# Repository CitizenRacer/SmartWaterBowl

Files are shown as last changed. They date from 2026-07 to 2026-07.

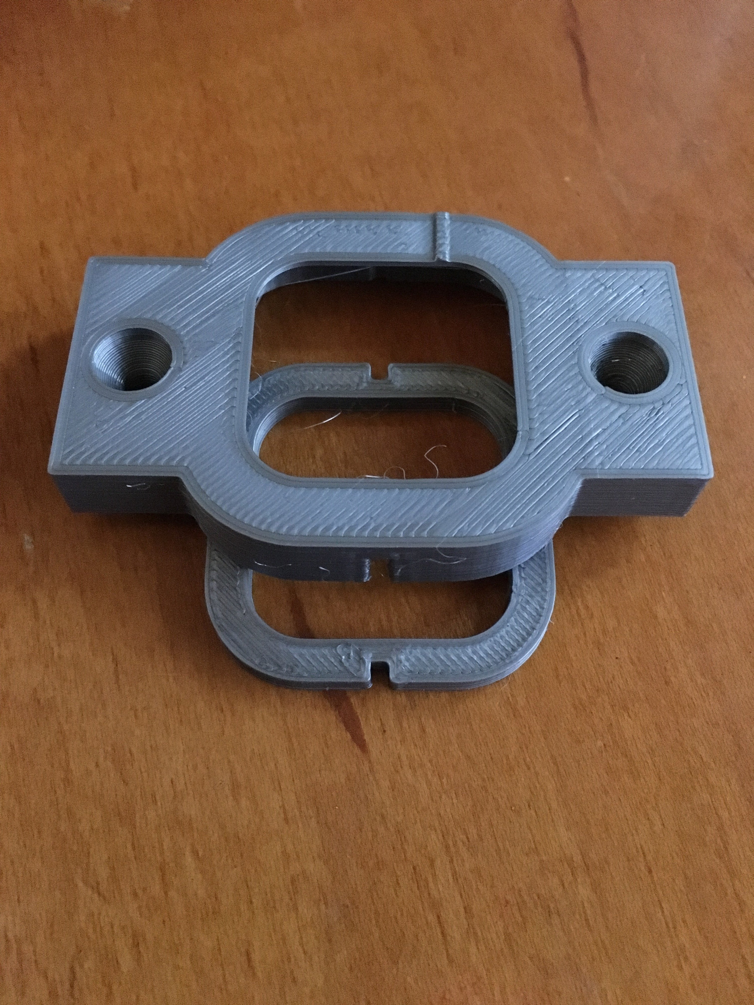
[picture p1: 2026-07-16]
hardware/loadcell-brackets/IMG_1209.jpg

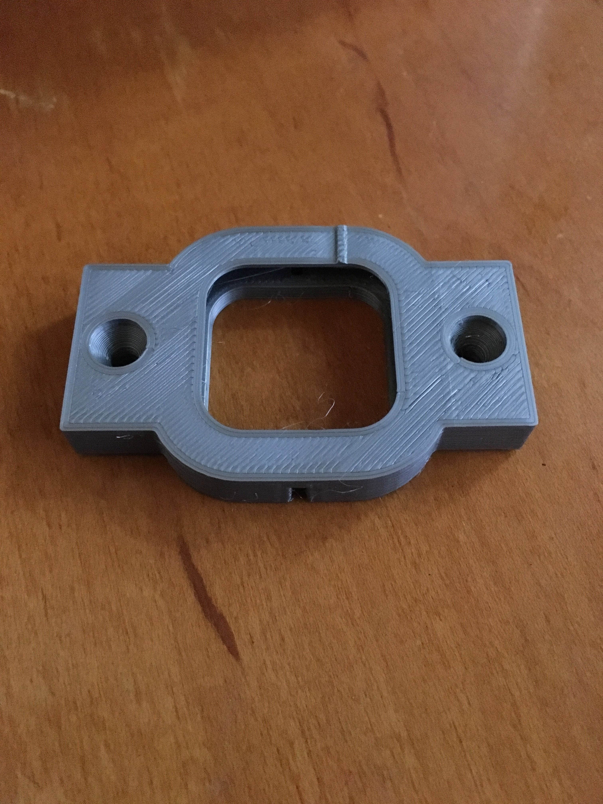
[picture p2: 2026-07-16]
hardware/loadcell-brackets/IMG_1208.jpg

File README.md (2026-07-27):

# SmartWaterBowl

SmartWaterBowl is an ESPHome-based scale for monitoring the amount of water in a shared dog bowl and publishing the measurements to Home Assistant. The repository also includes an optional clip-on fountain-tube mount for circulating water back into the bowl.

Four load sensors support the bowl platform. Their signals are combined, digitized by an HX711 amplifier, and read by an ESP32-S3 running ESPHome.

> **Current status:** The enclosure fit and ESP32 cradle fit were physically verified in earlier revisions, including the V35 ESP32 geometry retained in the current **V40** source. V40 replaces the diagonal HX711 support reliefs with horizontal east-west flats: the southern support pair faces north and the northern support pair faces south. The load-cell bracket design, repaired STL files, initial ESPHome firmware, and parametric fountain-tube mount are tracked in the repository; V40 physical validation, wiring validation, calibration, the bowl platform, and physical validation of the fountain mount remain in development.

## System overview

```text
Water bowl and platform
        ↓
4 × load sensors in printed brackets
        ↓
SparkFun Load Sensor Combinator
        ↓
SparkFun HX711 Load Cell Amplifier
        ↓
ESP32-S3 SuperMini running ESPHome
        ↓
Home Assistant
```

## Project goals

- Measure the current amount of water in the bowl.
- Track water added and water consumed over time.
- Publish measurements to Home Assistant through ESPHome.
- Keep powered electronics protected in a separate enclosure.
- Make the mechanical and electronics mounting parts reproducible with a 3D printer.
- Support an optional low-voltage recirculating fountain with a removable, rigidly supported tube path.

## Hardware

| Component | Purpose |
|---|---|
| 4 × SparkFun 50 kg load sensors | Support and weigh the bowl platform |
| 3D-printed load-cell brackets | Hold each load sensor and transfer platform load |
| SparkFun Load Sensor Combinator | Combines the four load sensors into one bridge output |
| SparkFun HX711 Load Cell Amplifier | Digitizes the load-cell signal |
| ESP32-S3 SuperMini | Runs ESPHome and publishes measurements over Wi-Fi |
| LeMotech 115 × 90 × 55 mm enclosure — Amazon ASIN `B0895J3SWL` | Protects the electronics |
| USB-C panel-mount extension | Provides external power and programming access |
| PG7 cable glands | Seal the load-sensor cable entries |
| 22 AWG silicone wire | Internal wiring |
| JST-PH connectors | Provide disconnectable internal connections |
| M3 × 6 mm machine screws | Permanently secure the two SparkFun boards directly to printed plastic bosses |
| Optional low-voltage submersible pump and 10 mm OD tubing | Recirculate water through the clip-on fountain mount |

## Repository layout

```text
firmware/
└── esphome_water_bowl.yaml
hardware/
├── enclosure/
│   └── water_bowl_electronics_carrier.scad
├── fountain/
│   └── water_bowl_fountain_mount.scad
└── loadcell-brackets/
    ├── 50kgLoadcell-VersionF.stl
    ├── 50kgLoadcell-VersionF-2021.stl
    ├── source CAD and preview images
    ├── README.txt
    └── LICENSE.txt
```

Additional directories will be added as wiring documentation and the bowl-platform design are completed.

## ESPHome firmware

The current ESPHome configuration is:

[`firmware/esphome_water_bowl.yaml`](firmware/esphome_water_bowl.yaml)

It currently provides:

- Current water-only weight after subtracting a configurable empty-bowl weight
- Latest settled refill weight, used as the 100% reference
- Percentage full based on the most recent qualifying refill
- Timestamp of the last manual or automatic tare
- A Home Assistant tare button
- Automatic tare detection after a drop greater than one pound, confirmed only after the platform remains near zero for five seconds
- Refill detection requiring approximately eight fluid ounces of added water and a five-second settling period

The initial pin assignment is:

| HX711 signal | ESP32-S3 pin |
|---|---|
| DOUT | GPIO5 |
| CLK | GPIO6 |

The `counts_per_lb` substitution is currently a placeholder and must be replaced after physical calibration. Wi-Fi, API encryption, OTA, and fallback access-point credentials are expected in the ESPHome secrets file.

## Electronics carrier

The current carrier source is:

[`hardware/enclosure/water_bowl_electronics_carrier.scad`](hardware/enclosure/water_bowl_electronics_carrier.scad)

The filename remains stable across revisions. The printed revision is controlled by the `board_version` value inside the SCAD file and is physically raised on the carrier.

The current board revision is **V40**.

### Supported hardware

The carrier is designed for the LeMotech 115 × 90 × 55 mm enclosure, Amazon ASIN `B0895J3SWL`, and holds:

- SparkFun Load Sensor Combinator
- SparkFun HX711 Load Cell Amplifier
- ESP32-S3 SuperMini

### Carrier features

- Four measured 3.4 mm enclosure mounting holes
- Four support locations per SparkFun board
- Two diagonal M3 screw bosses and two diagonal locator pins per SparkFun board
- Printed 2.80 mm thread-forming pilot holes for M3 screws, so no drilling is required
- Pilot holes extend 1.0 mm into the 2.0 mm carrier base while leaving a 1.0 mm floor
- East-west relief flats on all four HX711 support pads for clearance around soldered underside pins
- North-facing flats on the two southern HX711 supports and south-facing flats on the two northern supports
- Each HX711 flat is tangent to the 3.18 mm central post envelope
- Fully round, unchanged support pads for the Load Sensor Combinator
- Captured-rail cradle for the ESP32-S3 SuperMini
- Physically verified V35 ESP32 cradle position preserved unchanged
- 0.635 mm ESP32 header-pin channels, sized for measured 0.63 mm-wide pins
- Two pairs of optional zip-tie slots
- Raised board-revision marking
- Thin `fit_check` mode for verifying enclosure fit before printing the complete carrier
- Validation that rejects unsupported `mode` values instead of silently producing an incomplete part

The M3 × 6 mm screws are intended to form threads directly in the printed plastic. The 2.80 mm holes are thread-forming pilots, not clearance holes: an M3 screw should be driven into them rather than dropping freely through. Because the boards are not expected to be removed after assembly, this avoids heat-set inserts while still providing positive retention. Tighten the screws only until the boards are secure; excessive torque can strip the printed threads or damage the PCB.

V38 increased the pilot-hole diameter from 2.55 mm to 2.80 mm after the V37 print accepted an M2.5 screw but was too tight for the intended M3 fastener.

V39 introduced reliefs on all four HX711 support pads, but oriented each flat diagonally toward the board center. V40 corrects the orientation without changing the relief depth: both flats on the southern row run east-west and face north, while both flats on the northern row run east-west and face south. The Load Sensor Combinator supports, board coordinates, support heights, M3 pilots, locator pins, ESP32 cradle, zip-tie slots, and enclosure geometry remain unchanged.

The enclosure mounting-hole coordinates are expressed in the final carrier-local coordinate frame and were adjusted empirically against the enclosure. Changing `wall_clearance` requires revalidating those four coordinates.

The current design omits the earlier side-retention bumps because their geometry did not reach the nominal enclosure wall. The carrier is secured by the four enclosure mounting screws.

### Generating the carrier

1. Open the SCAD file in [OpenSCAD](https://openscad.org/).
2. Set the mode near the top of the file:

   ```scad
   mode = "carrier";
   ```

   Available modes:

   - `"fit_check"` creates a thin enclosure-fit test plate without the board holders.
   - `"carrier"` creates the complete electronics carrier.

   Any other value stops rendering with an explanatory assertion error.

3. Render the model with **F6**.
4. Export it as an STL.
5. Slice and print it flat on the build plate.

Suggested starting print settings:

- 0.20 mm layer height or finer
- At least three walls
- PLA, PETG, or ASA

PETG or ASA should provide more durable screw threads than brittle PLA, but PLA is acceptable for a one-time installation when the screws are tightened carefully.

Confirm dimensions, tolerances, and material suitability for the actual enclosure and operating environment before committing to a complete build.

## Load-cell brackets

The selected bracket design is **50kg Loadcell Bracket versionF** by Thingiverse user **patrick3345**:

- Original source: <https://www.thingiverse.com/thing:2624188>
- License: Creative Commons Attribution, as stated in the supplied `LICENSE.txt`
- Preserved attribution and source files: [`hardware/loadcell-brackets/`](hardware/loadcell-brackets/)

The two STL files in this directory have been repaired for reliable slicing while retaining their original filenames. The original README, license, source CAD files, preview images, and project fit-test photos remain beside them so attribution and design context stay together.

## Fountain tube mount

The optional fountain mount source is:

[`hardware/fountain/water_bowl_fountain_mount.scad`](hardware/fountain/water_bowl_fountain_mount.scad)

It is a parametric clip-on guide for nominal 10 mm OD flexible tubing. The tube follows an open candy-cane-shaped trough, rises 100 mm above the bowl rim, curves over the bowl, and points the outlet downward and inward. The groove is cut through at both ends so the tubing can sit at full depth throughout the guide. Three pairs of slots accept small zip ties for removable retention.

The key dimensions near the top of the file are:

```scad
tube_od = 10.0;
bowl_rim_thickness = 6.0;
riser_height_above_rim = 100.0;
bend_radius = 22.0;
outlet_inward_angle = 25.0;
outlet_length = 33.0;
```

Measure the actual bowl rim and tubing before printing. Print the mount with its broad flat rear face on the build plate and the tube groove facing upward. The model is intended to print without supports. PETG or ASA is preferred for durability around water and repeated clipping, but material and tubing suitability for the intended water-contact environment must be evaluated before use.

## Current progress

- [x] Select the load sensors and electronics
- [x] Purchase the core electronics and wiring hardware
- [x] Measure the LeMotech enclosure
- [x] Design and fit-test the electronics carrier
- [x] Preserve the physically verified V35 ESP32 holder geometry
- [x] Create carrier board revision V40
- [x] Replace ineffective snap tabs with direct-threaded M3 board retention
- [x] Remove ineffective side-retention bumps
- [x] Deepen the printed M3 pilot holes while retaining a solid base floor
- [x] Increase the SparkFun-board pilot holes to 2.80 mm for M3 thread forming
- [x] Add HX711 support relief for soldered underside-pin clearance
- [x] Orient the southern HX711 reliefs north and the northern reliefs south
- [x] Keep the Load Sensor Combinator supports unchanged
- [x] Adopt a stable carrier filename independent of board revision
- [x] Select and archive the load-cell bracket design with attribution
- [x] Repair the bracket STL files for slicing
- [x] Select initial ESP32 pin assignments
- [x] Add the initial ESPHome configuration
- [x] Add the parametric clip-on fountain tube mount source
- [ ] Physically print and validate carrier board revision V40
- [ ] Physically print and validate the fountain mount against the bowl and tubing
- [ ] Integrate the brackets into the bowl platform
- [ ] Validate the wiring and pin assignments on assembled hardware
- [ ] Calibrate the assembled scale
- [ ] Add Home Assistant dashboards and automations
- [ ] Validate long-term stability and water resistance

## Versioning convention

The carrier filename does not include a revision number. Future carrier revisions will continue to use:

```text
hardware/enclosure/water_bowl_electronics_carrier.scad
```

The revision number must instead be updated in the SCAD file:

```scad
board_version = "V40";
```

This value is rendered directly onto the printed carrier, making the physical revision identifiable without changing repository paths or documentation links.

The fountain mount also uses a stable descriptive path:

```text
hardware/fountain/water_bowl_fountain_mount.scad
```

## Repository maintenance

Every repository change should include a review of this README to verify that it remains factually correct and easy to understand. Update it whenever a change affects:

- File or directory names
- Hardware selections
- Board revision or mechanical design
- Wiring or pin assignments
- ESPHome configuration
- Calibration procedure
- Build status or remaining work

Readability improvements should be made whenever they clarify setup, operation, or project status.

## Calibration plan

Once assembled, the scale will need at least two calibration points:

1. Record the unloaded HX711 reading with the empty platform installed.
2. Place a known calibration weight on the platform and record the loaded reading.
3. Use those values to calculate the scale factor in ESPHome.
4. Verify the result with several known weights across the expected operating range.

The scale should be tared with the permanent platform hardware installed but without the removable bowl. Enter the empty bowl's measured weight using the `Bowl Weight` entity so the published weight represents water only.

## Water protection

This project places powered electronics near a water bowl. Use only low-voltage power, route cables through sealed glands, provide strain relief, and keep the electronics enclosure physically separated from areas where spilled water can collect.

The printed electronics carrier, load-cell brackets, and fountain mount are mechanical parts and are not themselves waterproof barriers. Use pump, tubing, fasteners, and printed materials suitable for the intended water-contact environment, and inspect and clean the fountain components regularly.

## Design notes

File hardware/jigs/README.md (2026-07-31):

# Smart Water Bowl fabrication jigs

This folder contains printable OpenSCAD jigs used to locate holes and repeat critical fabrication steps for the Smart Water Bowl hardware.

Generated STL files are intentionally not stored in the repository. Open the desired `.scad` file in OpenSCAD, render it with **F6**, and export an STL locally.

## `water_bowl_corner_hole_jig.scad`

### Purpose

Locates the two mounting holes for each 50 kg load-cell bracket at the four corners of the 16 × 11 × 1 inch cutting-board scale platform.

### Critical geometry

- Two 2.2 mm marking holes
- Mounting-hole spacing: 44.0 mm center to center
- Pattern center: 38.0 mm from each adjacent board edge
- Sized for a nominal 25.4 mm-thick cutting board
- Small inside-corner relief for rounded or beveled board edges
- Raised marking collars disabled with `collar_h = 0`

### Use

1. Place the jig on the underside of one cutting-board corner.
2. Seat both fences firmly against the adjacent board edges.
3. Keep the 82 mm side parallel to the board's 16-inch edge.
4. Mark through both holes with an awl, transfer punch, or a small drill bit turned by hand.
5. Rotate the jig around the board and repeat at all four corners.

### Printing

Print with the flat top plate on the build plate and the fences extending upward. No supports should be required.

Suggested starting settings:

- 0.20 mm layer height
- Four walls
- 25% infill
- PETG or ASA preferred; PLA is adequate for a temporary jig

### Validation note

The 44.0 mm mounting-hole spacing is the current prototype value. Compare a printed jig directly against a printed load-cell bracket before drilling the cutting board.

### Bracket attribution

The mounting geometry is based on **50kg Loadcell Bracket versionF** by Thingiverse user **patrick3345** (Patrick Laidlaw):

- Original source: https://www.thingiverse.com/thing:2624188
- License: Creative Commons Attribution, as preserved in `hardware/loadcell-brackets/LICENSE.txt`

## `water_bowl_enclosure_pilot_hole_jig.scad`

### Purpose

Locates the two cable-entry pilot holes, one in each long side of the LeMotech 115 × 90 × 55 mm enclosure base.

The holes align with the cable zip-tie pairs on `hardware/enclosure/water_bowl_electronics_carrier.scad`. The jig indexes from one outside short end of the enclosure and places both side holes at the same longitudinal station.

### Critical geometry

- Pilot-hole station: 43.85 mm from the indexed outside end
- Pilot-hole center height: 12 mm above the enclosure's outside bottom
- Printed locating-hole diameter: 3.30 mm for a nominal 1/8-inch pilot bit
- Flat drilling walls with no projecting bosses
- Short-end stop for repeatable positioning

The 43.85 mm station is derived from the enclosure wall thickness, carrier end clearance, and carrier zip-tie geometry. Those values are documented in the OpenSCAD source and should remain synchronized with the carrier design.

### Use

1. Print the jig flat on its bottom frame.
2. Place the empty enclosure base in the jig.
3. Press the selected short end firmly against the end stop.
4. Clamp the enclosure and jig together.
5. Drill through both flat pilot-hole locators.
6. Remove the jig.
7. Enlarge each enclosure hole to its final diameter with a step drill.

Do not run the step drill through the printed jig. The jig is only intended to establish the pilot-hole centers.

### Printing

Print exactly as modeled with the bottom frame on the build plate. The side walls are flat and no supports should be required.

PETG or ASA is recommended for better heat resistance and durability.

### Adjustable parameters

The main user-adjustable values near the top of the OpenSCAD file are:

- `pilot_d`
- `hole_height_from_bottom`
- `side_clearance`
- `side_wall_t`
- `side_wall_h`

## Adding another jig

Use a descriptive filename without a revision number. Add a section here that documents:

- What the jig is for
- The surfaces or edges it indexes from
- Critical dimensions
- Print orientation and support requirements
- How to use it
- Any measurements that must stay synchronized with another project file

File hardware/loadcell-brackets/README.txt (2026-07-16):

50kg Loadcell Bracket versionF by patrick3345 on Thingiverse: https://www.thingiverse.com/thing:2624188

Summary:
50kg Load Cell Bracket.  insert load cell and base into the holder and screw it down.

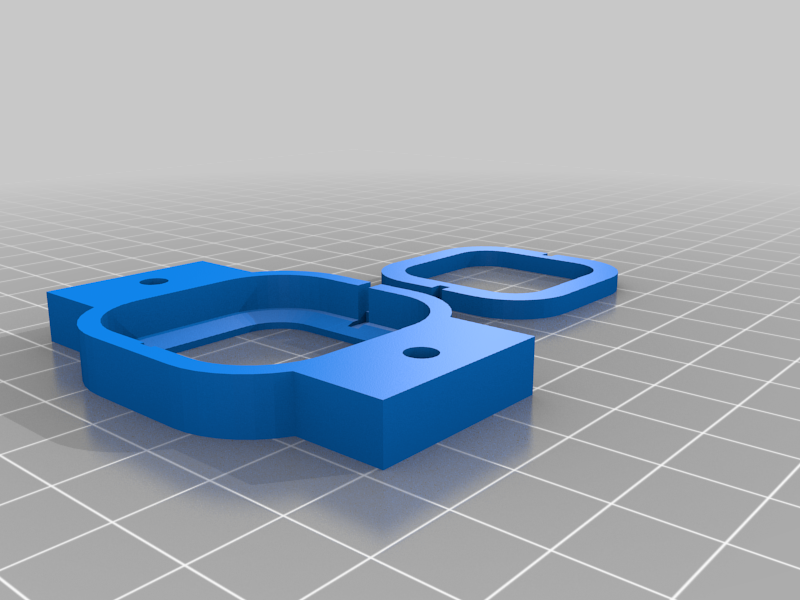
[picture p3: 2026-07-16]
hardware/loadcell-brackets/50kgLoadcell-VersionF-2021.png

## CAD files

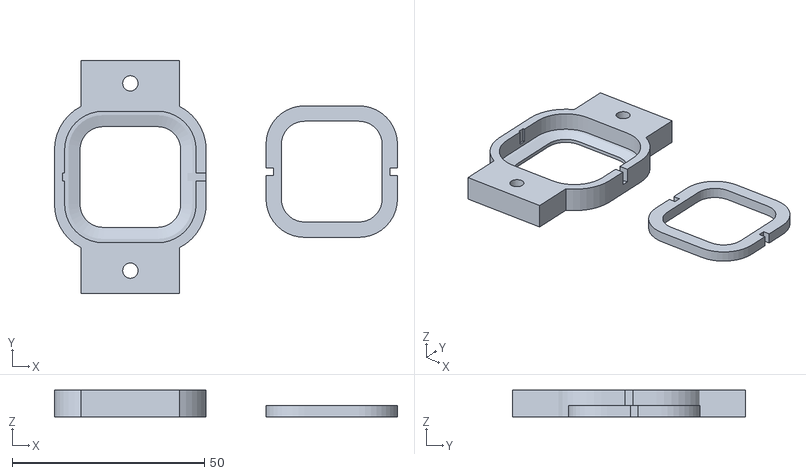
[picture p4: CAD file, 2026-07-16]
hardware/loadcell-brackets/50kgLoadcell-VersionF-2021.stl
89.2 x 60.7 x 7.00

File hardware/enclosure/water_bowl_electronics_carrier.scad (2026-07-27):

/*
ChatGPT ESPHome Water Bowl Scale
LeMotech 115 x 90 x 55 mm electronics carrier - V40
LeMotech enclosure Amazon ASIN: B0895J3SWL

V40 change from V39:
- Replaced the diagonal HX711 support-pad reliefs with east-west flat faces.
- The two southern HX711 supports have north-facing flats; the two northern supports have south-facing flats.
- Each flat is tangent to the outside of the 3.18 mm central post envelope.
- The Load Sensor Combinator supports and all other V39 geometry are unchanged.

Units and coordinate conventions:
- All dimensions are millimeters unless otherwise noted.
- X increases from the carrier's left edge to its right edge (west to east).
- Y increases from the carrier's lower end toward its upper end (south to north).
- Z increases upward from the bottom face of the printed carrier.
- Board positions and enclosure mounting-hole coordinates use the final carrier-local frame.

Fit-sensitive geometry:
- The ESP32 cradle position and 0.635 mm pin channels were physically verified in V35.
- The four enclosure mounting-hole coordinates were adjusted empirically against the enclosure.
- Do not alter those values without another physical fit test.
*/

$fn = 96;  // Facet count for cylinders; higher values look smoother but render more slowly.

// ---------- Output and plate settings ----------

// Selects the generated part:
// - "carrier": complete electronics carrier with board mounts and ESP32 cradle.
// - "fit_check": thin outline plate for checking enclosure fit only.
mode = "carrier";

// Text physically raised on the printed carrier.
board_version = "V40";

// Thickness of the complete carrier plate in "carrier" mode.
base_t = 2.0;

// Thickness of the reduced-cost enclosure test plate in "fit_check" mode.
fit_check_t = 1.0;

// Clearance removed from EACH side of the nominal enclosure interior dimensions.
// Increasing this reduces the finished carrier's width and length. The mounting-hole
// coordinates below do not automatically compensate and must then be revalidated.
wall_clearance = 0.65;

// Optional circular removal holes near the narrow end tabs. Disabled in V40.
finger_holes = false;

// Enables the two pairs of through-slots used for optional cable or component zip ties.
zip_tie_slots = true;

// Short dimension of each rectangular zip-tie slot.
zip_tie_slot_w = 2.4;

// Long dimension of each rectangular zip-tie slot.
zip_tie_slot_l = 10.0;

// Center-to-center Y separation between the two slots in each pair.
zip_tie_pair_spacing = 10.0;

// Enables the four enclosure-screw clearance holes in the carrier plate.
mount_holes = true;

// Diameter of each enclosure mounting through-hole; sized as M3 screw clearance.
mount_hole_d = 3.40;

// Enclosure mounting-hole centers in the FINAL carrier-local [X,Y] frame.
// These values were adjusted empirically against the physical LeMotech enclosure.
// Changing wall_clearance or the carrier outline requires revalidating all four points.
mount_points = [
    [5.98, 93.00],   // Upper-left enclosure mounting hole.
    [74.54, 93.13],  // Upper-right enclosure mounting hole.
    [6.38, 15.10],   // Lower-left enclosure mounting hole.
    [74.64, 15.07]   // Lower-right enclosure mounting hole.
];

// ---------- SparkFun board supports and fasteners ----------

// Height from the carrier's top surface to the underside of each SparkFun PCB.
standoff_h = 5.0;

// Outside diameter of every circular SparkFun support pad / screw boss.
standoff_od = 6.4;

// Printed thread-forming pilot diameter for M3 machine screws.
// This is intentionally smaller than the screw's 3.0 mm major diameter; the screw
// forms its own threads during the one-time installation rather than dropping through.
m3_pilot_d = 2.80;

// Additional pilot-hole depth below the top surface of the 2.0 mm carrier plate.
// At 1.0 mm this leaves a solid 1.0 mm floor beneath the hole.
m3_pilot_into_plate = 1.0;

// Diameter of the straight section of each non-threaded SparkFun locator pin.
prototype_pin_d = 3.18;

// Total locator-pin height above its circular support pad.
prototype_pin_h = 3.20;

// Height of the tapered lead-in at the top of each locator pin.
prototype_tip_h = 0.60;

// Diameter at the narrow top end of each locator-pin taper.
prototype_tip_d = 2.75;

// The HX711 pad relief stops at a tangent to this narrow central envelope.
hx_support_relief_d = prototype_pin_d;

// ---------- ESP32-S3 SuperMini cradle ----------

// Nominal free space added around each side of the ESP32 PCB envelope.
esp_clearance = 0.20;

// Thickness of each outside cradle rail surrounding the ESP32.
esp_rail_t = 1.40;

// Height of the outside cradle rails above the carrier plate.
esp_rail_h = 3.2;

// Gap between each outer and inner rail that captures an ESP32 header-pin row.
// This 0.635 mm value is intentionally retained from the physically verified V35 fit.
esp_pin_channel_w = 0.635;

// Thickness of each inner rail on the board side of a header-pin channel.
esp_inner_rail_t = 1.00;

// Height of each inner rail above the carrier plate.
esp_inner_rail_h = 3.20;

// Distance that each inner rail stops short of both cradle ends, allowing insertion.
esp_inner_rail_end_clearance = 1.50;

// ---------- Raised revision marking ----------

// Character size of the raised board revision text.
version_text_size = 5.0;

// Amount that the revision text rises above the carrier's top surface.
version_text_height = 0.60;

// Amount that the text extrusion overlaps the plate to guarantee a fused solid.
version_text_embed = 0.10;

// OpenSCAD font specification for the raised revision marking.
version_text_font = "Liberation Sans:style=Bold";

// [X,Y] anchor point for the revision text in the carrier-local frame.
version_text_pos = [8, 20];

// ---------- Enclosure and carrier outline ----------

// Nominal usable inside width of the LeMotech enclosure.
inner_w = 82.0;

// Nominal usable inside length of the LeMotech enclosure.
inner_h = 109.0;

// Nominal Y length of the wide middle section between the two narrow end tabs.
clear_middle_h = 87.0;

// Nominal X width of the narrow throat at each end of the enclosure.
end_throat_w = 46.0;

// Finished carrier width after removing wall_clearance from both left and right sides.
carrier_w = inner_w - 2*wall_clearance;

// Finished carrier length after removing wall_clearance from both ends.
carrier_h = inner_h - 2*wall_clearance;

// Finished Y length of the wide middle section after end clearances are applied.
middle_h = clear_middle_h - 2*wall_clearance;

// Finished X width of each narrow end tab.
end_tab_w = end_throat_w - 2*wall_clearance;

// Derived Y length of each narrow end tab; the upper and lower tabs are equal.
end_tab_h = (carrier_h-middle_h)/2;

// Left X boundary of each centered narrow end tab.
end_x0 = (carrier_w-end_tab_w)/2;

// Right X boundary of each centered narrow end tab.
end_x1 = end_x0+end_tab_w;

// Y coordinate where the lower narrow tab transitions into the wide center section.
mid_y0 = end_tab_h;

// Y coordinate where the wide center section transitions into the upper narrow tab.
mid_y1 = carrier_h-end_tab_h;

// ---------- Electronics board dimensions and positions ----------

// SparkFun Load Sensor Combinator nominal PCB width and height.
comb_w = 30.48;
comb_h = 27.94;

// SparkFun HX711 Load Cell Amplifier nominal PCB width and height.
hx_w = 30.48;
hx_h = 22.86;

// ESP32-S3 SuperMini PCB dimensions as used by the rotated cradle geometry.
// esp_y becomes the cradle's local X dimension; esp_x becomes its local Y dimension.
esp_x = 18.034;
esp_y = 25.4;

// Lower-left local origin of each SparkFun board footprint in carrier coordinates.
comb_pos = [7.0, 59.46];
hx_pos = [44.0, 62.0];

// Intentionally preserves the physically verified V35 ESP32 fit. This position uses
// the historical cradle origin rather than recentering the clearance envelope.
// Do not recenter or alter it without another physical fit test.
esp_pos = [(carrier_w-esp_y)/2, 14.0];

// SparkFun Combinator mounting-hole centers relative to comb_pos.
// Indices 0 and 3 receive M3 screw bosses; indices 1 and 2 receive locator pins.
comb_holes = [
    [27.94, 2.54],
    [2.54, 2.54],
    [27.94, 25.40],
    [2.54, 25.40]
];

// SparkFun HX711 mounting-hole centers relative to hx_pos.
// Hole order: lower-left, upper-left, lower-right, upper-right.
// Indices 0 and 3 receive M3 screw bosses; indices 1 and 2 receive locator pins.
hx_holes = [
    [2.54, 2.54],
    [2.54, 20.32],
    [27.94, 2.54],
    [27.94, 20.32]
];

// Relief-face direction for each HX711 support in the same order as hx_holes.
// The lower (southern) row faces north; the upper (northern) row faces south.
hx_relief_faces = ["north", "south", "north", "south"];

// ---------- Geometry modules ----------
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

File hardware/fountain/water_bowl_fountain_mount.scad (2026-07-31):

/*
  ChatGPT_Dog_Bowl_Candy_Cane_100mm_Lip_Hook.scad

  Revision of the original 100 mm candy-cane fountain holder.
  Keeps the original candy-cane trough, open ends, angled outlet, zip-tie
  slots, and flat print orientation. Replaces only the old thick-wall U-clip
  with a simple gravity hook for a stainless lip about 12.7 mm wide and
  1.6-3.2 mm thick. This revision removes the underside spring tab entirely.
*/

$fn = 48;

// Tubing
tube_od = 10.0;
tube_clearance = 0.35;
groove_depth = 5.6;

// Thin stainless bowl lip
lip_width = 12.7;
lip_width_clearance = 1.2;
lip_thickness_max = 3.2;
lip_vertical_clearance = 0.8;

// Hook structure
outside_leg_thickness = 4.0;
outside_leg_length = 28.0;   // Shorter, cleaner exterior leg
top_bridge_thickness = 5.0;
inside_stop_thickness = 3.5;
inside_stop_drop = 8.0;

// Overall printed thickness
part_depth = 12.0;

// Original candy-cane dimensions
riser_height_above_rim = 100.0;
bend_radius = 22.0;
outlet_inward_angle = 25.0;
outlet_length = 33.0;
end_groove_extension = 12.0;
guide_overlap = 3.0;
guide_side_wall = 3.0;
guide_extra_for_ties = 2.0;

// Zip ties
include_zip_tie_slots = true;
zip_tie_width = 3.2;
zip_tie_slot_clearance = 0.5;
zip_tie_slot_cross = 2.0;
zip_tie_side_offset = 2.0;

// Preview helpers
show_tube_preview = false;
show_lip_preview = false;

// Derived values
lip_gap_x = lip_width + lip_width_clearance;
lip_gap_y = lip_thickness_max + lip_vertical_clearance;

hook_inside_x = outside_leg_thickness + lip_gap_x;
hook_total_x = hook_inside_x + inside_stop_thickness;

hook_top_y = outside_leg_length;
lip_underside_y = hook_top_y - lip_gap_y;
inside_stop_bottom_y = hook_top_y - inside_stop_drop;

tube_r = tube_od / 2 + tube_clearance;
guide_half_width = tube_r + guide_side_wall + guide_extra_for_ties;

// Positive X points into the bowl.
riser_x = hook_total_x + guide_half_width - guide_overlap;
riser_start_y = 3.0;
riser_top_y = hook_top_y + top_bridge_thickness + riser_height_above_rim;

arc_center_x = riser_x + bend_radius;
arc_center_y = riser_top_y;
arc_end_angle = outlet_inward_angle;
outlet_direction = arc_end_angle - 90.0;

groove_center_z = part_depth + tube_r - groove_depth;

function arc_points(cx, cy, r, a0, a1, count) =
    [for (i = [0 : count])
        [cx + r * cos(a0 + (a1 - a0) * i / count),
         cy + r * sin(a0 + (a1 - a0) * i / count)]];

arc_path = arc_points(arc_center_x, arc_center_y, bend_radius, 180, arc_end_angle, 24);
arc_end = arc_path[len(arc_path) - 1];
outlet_end = [
    arc_end[0] + outlet_length * cos(outlet_direction),
    arc_end[1] + outlet_length * sin(outlet_direction)
];

tube_path = concat(
    [[riser_x, riser_start_y], [riser_x, riser_top_y]],
    arc_path,
    [outlet_end]
);

groove_start = [riser_x, riser_start_y - end_groove_extension];
groove_end = [
    outlet_end[0] + end_groove_extension * cos(outlet_direction),
    outlet_end[1] + end_groove_extension * sin(outlet_direction)
];
groove_path = concat([groove_start], tube_path, [groove_end]);

module stroke_2d(points, radius) {
    union() {
        for (i = [0 : len(points) - 2]) {
            hull() {
                translate(points[i]) circle(r = radius);
                translate(points[i + 1]) circle(r = radius);
            }
        }
    }
}

module swept_spheres(points, radius, z_center) {
    union() {
        for (i = [0 : len(points) - 2]) {
            hull() {
                translate([points[i][0], points[i][1], z_center]) sphere(r = radius);
                translate([points[i + 1][0], points[i + 1][1], z_center]) sphere(r = radius);
            }
        }
    }
}

module bowl_hook_profile_2d() {
    union() {
        // Long outside structural leg.
        square([outside_leg_thickness, hook_top_y + top_bridge_thickness]);

        // Bridge rests across the 1/2-inch rolled lip.
        translate([0, hook_top_y])
            square([hook_total_x, top_bridge_thickness]);

        // Short inside stop only; no full inner clamping leg.
        translate([hook_inside_x, inside_stop_bottom_y])
            square([
                inside_stop_thickness,
                hook_top_y + top_bridge_thickness - inside_stop_bottom_y
            ]);

        // Lead-in at bottom of outside leg.
        polygon(points = [
            [0, 0],
            [outside_leg_thickness, 0],
            [outside_leg_thickness, 4.0],
            [outside_leg_thickness - 1.2, 2.0]
        ]);
    }
}

module slot_pair_at(point, tangent_angle) {
    slot_along = zip_tie_width + zip_tie_slot_clearance;
    side_distance = tube_r + zip_tie_side_offset;

    for (normal_offset = [-side_distance, side_distance]) {
        translate([point[0], point[1], part_depth / 2])
            rotate([0, 0, tangent_angle])
                translate([0, normal_offset, 0])
                    cube([
                        slot_along,
                        zip_tie_slot_cross,
                        part_depth + 0.4
                    ], center = true);
    }
}

module all_zip_tie_slots() {
    if (include_zip_tie_slots) {
        slot_pair_at([riser_x, 19.0], 90);
        slot_pair_at([riser_x, riser_top_y - 12.0], 90);

        outlet_mid = [
            arc_end[0] + outlet_length * 0.52 * cos(outlet_direction),
            arc_end[1] + outlet_length * 0.52 * sin(outlet_direction)
        ];
        slot_pair_at(outlet_mid, outlet_direction);
    }
}

module solid_mount() {
    union() {
        linear_extrude(height = part_depth)
            bowl_hook_profile_2d();

        linear_extrude(height = part_depth)
            stroke_2d(tube_path, guide_half_width);

        // Revised gusset joins the original riser to the new hook.
        linear_extrude(height = part_depth)
            hull() {
                translate([
                    hook_inside_x + inside_stop_thickness / 2,
                    inside_stop_bottom_y + 2.5
                ]) circle(r = 3.0);

                translate([riser_x, 12.0])
                    circle(r = guide_half_width - 1.0);

                translate([
                    hook_inside_x + inside_stop_thickness / 2,
                    hook_top_y + top_bridge_thickness - 2.0
                ]) circle(r = 3.0);

                translate([
                    riser_x,
                    hook_top_y + top_bridge_thickness + 2.0
                ]) circle(r = guide_half_width - 1.0);
            }
    }
}

module fountain_mount() {
    difference() {
        solid_mount();
        swept_spheres(groove_path, tube_r, groove_center_z);
        all_zip_tie_slots();
    }
}

fountain_mount();

if (show_tube_preview) {
    %swept_spheres(
        tube_path,
        tube_od / 2,
        part_depth + tube_od / 2 - groove_depth
    );
}

if (show_lip_preview) {
    %color([0.65, 0.68, 0.72, 0.55])
        translate([
            outside_leg_thickness,
            hook_top_y - lip_thickness_max,
            -1
        ])
            cube([lip_width, lip_thickness_max, part_depth + 2]);

    %color([0.65, 0.68, 0.72, 0.35])
        translate([
            outside_leg_thickness + lip_width - 1.2,
            hook_top_y - lip_thickness_max - 35,
            -1
        ])
            cube([1.2, 35, part_depth + 2]);
}

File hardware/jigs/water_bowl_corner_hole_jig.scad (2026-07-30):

/*
ESPHome Water Bowl Scale
Corner Hole-Marking Jig v1.0 for a 16 x 11 x 1 inch cutting-board platform

Bracket source used for mounting geometry:
50kg Loadcell Bracket versionF by Patrick Laidlaw (patrick3345)
https://www.thingiverse.com/thing:2624188
CC BY, as preserved in the SmartWaterBowl repository.

Use:
- Put the jig on the UNDERSIDE of one board corner.
- Keep the 82 mm side parallel to a 16 inch edge.
- Push both fences fully against the board.
- Mark through both 2.2 mm guide holes with an awl or transfer punch.
- Rotate the physical jig around the board, always keeping the 82 mm side
  parallel to a 16 inch edge.

The two guide-hole centers are parameterized below so they can be revised after
an actual printed-foot fit check without redesigning the jig.
*/

$fn = 64;

jig_version = "v1.0";

// Board
board_t = 25.4;              // 1 inch
fit_clearance = 0.45;        // each fence-to-board clearance

// Jig body
plate_x = 82.0;              // along the board's 16 inch edge
plate_y = 76.0;              // along the board's 11 inch edge
plate_t = 4.0;
fence_t = 4.0;
fence_drop = board_t + 3.0;
corner_relief = 2.0;

// Hole pattern, corner-local coordinates in mm.
// Hole axis is parallel to the 16 inch board edge.
hole_spacing = 44.0;
foot_center_x = 38.0;
foot_center_y = 38.0;
mark_hole_d = 2.2;
collar_od = 8.0;
collar_h = 0.0;

hole_a = [foot_center_x-hole_spacing/2, foot_center_y];
hole_b = [foot_center_x+hole_spacing/2, foot_center_y];

module rounded_rect_2d(w,h,r) {
    offset(r=r) square([w-2*r,h-2*r]);
}

module plate_2d() {
    difference() {
        rounded_rect_2d(plate_x, plate_y, 4);
        for (p=[hole_a,hole_b]) translate(p) circle(d=mark_hole_d);
    }
}

module jig() {
    difference() {
        union() {
            linear_extrude(plate_t) plate_2d();

            // Fences descend from the underside of the top plate.
            translate([0,-fence_t,-fence_drop])
                cube([plate_x+fence_t, fence_t, fence_drop+plate_t]);
            translate([-fence_t,0,-fence_drop])
                cube([fence_t, plate_y+fence_t, fence_drop+plate_t]);

            // Reinforced marking collars are disabled in v1.0.
            for (p=[hole_a,hole_b])
                translate([p[0],p[1],plate_t])
                    difference() {
                        cylinder(h=collar_h,d=collar_od);
                        translate([0,0,-0.1]) cylinder(h=collar_h+0.2,d=mark_hole_d);
                    }
        }

        // Inside-corner relief so a slightly radiused cutting-board edge does
        // not keep the fences from seating fully.
        translate([-0.1,-0.1,-fence_drop-0.1])
            cube([corner_relief,corner_relief,fence_drop+plate_t+0.2]);
    }
}

jig();

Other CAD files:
hardware/loadcell-brackets/50kgLoadcell-VersionF.stl
hardware/jigs/water_bowl_enclosure_pilot_hole_jig.scad
hardware/loadcell-brackets/50kgLoadcell-VersionF-2021.skp
hardware/loadcell-brackets/50kgLoadcell-VersionF-2021_v1-Fusion360.f3d
hardware/loadcell-brackets/50kgLoadcell-VersionF.skp

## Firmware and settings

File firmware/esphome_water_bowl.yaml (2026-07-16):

# ESPHome configuration for the SmartWaterBowl project.
#
# Hardware path:
#   4 load sensors -> SparkFun Load Sensor Combinator -> SparkFun HX711
#   -> ESP32-S3 SuperMini -> ESPHome/Home Assistant
#
# Reported entities:
#   - Current Weight: water-only weight after subtracting the configured bowl weight
#   - Max Weight Since Last Refill: settled water weight after the latest refill
#   - Percent Full: current water weight / latest settled refill weight
#   - Last Tare: timestamp of the most recent manual or automatic tare
#   - Bowl Weight: configurable empty-bowl weight
#   - Tare: Home Assistant button

substitutions:
  device_name: esphome-water-bowl
  friendly_name: Water Bowl Scale

  # HX711 connections to the ESP32-S3 SuperMini.
  hx711_dout_pin: GPIO5
  hx711_clock_pin: GPIO6

  # Placeholder calibration factor. Replace this after physical calibration:
  # counts_per_lb = (raw_with_known_weight - raw_at_zero) / known_weight_lb
  counts_per_lb: "10000.0"

  # A refill must add at least 0.50 lb, approximately 8 US fluid ounces of water.
  refill_threshold_lb: "0.50"

  # Wait for the rising weight to stop changing before recording the refill.
  refill_settle_seconds: "5"

  # A drop larger than one pound arms auto-tare detection.
  auto_tare_drop_lb: "1.0"

  # Auto-tare is confirmed only if the platform then stays near zero.
  auto_tare_near_zero_lb: "0.25"
  auto_tare_stable_seconds: "5"

esphome:
  name: ${device_name}
  friendly_name: ${friendly_name}
  on_boot:
    priority: -100
    then:
      # Give networking and restored globals time to initialize, then publish
      # values that do not otherwise update until the first valid HX711 sample.
      - delay: 5s
      - lambda: |-
          id(max_weight_sensor).publish_state(id(max_weight_lb));
          id(last_tare_sensor).publish_state(id(last_tare_text));

esp32:
  # The SuperMini is compatible with the generic ESP32-S3 DevKit target.
  board: esp32-s3-devkitc-1
  framework:
    type: esp-idf

logger:

api:
  encryption:
    key: !secret api_encryption_key

ota:
  - platform: esphome
    password: !secret ota_password

wifi:
  ssid: !secret wifi_ssid
  password: !secret wifi_password

  # Temporary fallback access point if normal Wi-Fi is unavailable.
  ap:
    ssid: "${friendly_name} Fallback"
    password: !secret fallback_ap_password

captive_portal:

# SNTP time is used to stamp manual and automatic tare events.
time:
  - platform: sntp
    id: network_time
    timezone: America/Los_Angeles

# Home Assistant setting for the empty bowl's weight. The scale itself is
# tared with an empty platform; this value is then subtracted from gross weight
# so all published weight values represent water only.
number:
  - platform: template
    name: Bowl Weight
    id: bowl_weight
    icon: mdi:bowl
    unit_of_measurement: lb
    device_class: weight
    entity_category: config
    min_value: 0
    max_value: 20
    step: 0.01
    mode: box
    optimistic: true
    restore_value: true
    initial_value: 0

# Persistent and transient state used by tare, refill, and percentage logic.
globals:
  # Raw HX711 reading corresponding to an empty platform.
  - id: tare_offset_raw
    type: float
    restore_value: yes
    initial_value: "0.0"

  # Latest published water-only weight.
  - id: current_weight_lb
    type: float
    restore_value: no
    initial_value: "0.0"

  # Water weight captured after the most recent qualifying refill settles.
  - id: max_weight_lb
    type: float
    restore_value: yes
    initial_value: "0.0"

  # Prior samples are retained for drop and upward-trend detection.
  - id: previous_gross_weight_lb
    type: float
    restore_value: no
    initial_value: "NAN"

  - id: previous_water_weight_lb
    type: float
    restore_value: no
    initial_value: "NAN"

  # Human-readable tare timestamp, restored after reboot.
  - id: last_tare_text
    type: std::string
    restore_value: yes
    max_restore_data_length: 32
    initial_value: '"Never"'

  # Prevent immediate repeated auto-tares after a tare event.
  - id: last_tare_millis
    type: uint32_t
    restore_value: no
    initial_value: "0"

  # Refill state: baseline, highest candidate weight, and last increase time.
  - id: refill_pending
    type: bool
    restore_value: no
    initial_value: "false"

  - id: refill_baseline_lb
    type: float
    restore_value: no
    initial_value: "0.0"

  - id: refill_candidate_lb
    type: float
    restore_value: no
    initial_value: "0.0"

  - id: refill_last_increase_millis
    type: uint32_t
    restore_value: no
    initial_value: "0"

  # Auto-tare state. A large drop arms detection; a stable near-zero reading
  # confirms that the bowl/platform load was actually removed.
  - id: auto_tare_pending
    type: bool
    restore_value: no
    initial_value: "false"

  - id: auto_tare_near_zero_since
    type: uint32_t
    restore_value: no
    initial_value: "0"
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

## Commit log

2026-07-16 Add finalized V33 water bowl electronics carrier
    [ChatGPT_water_bowl_electronics_carrier_v33_latest_hole_positions.scad]
2026-07-16 Rename electronics carrier to stable filename
    [ChatGPT_water_bowl_electronics_carrier.scad]
2026-07-16 Set ESP32 pin channel gap to 0.635 mm
    [ChatGPT_water_bowl_electronics_carrier.scad]
2026-07-16 Restore SparkFun board locking posts
    [ChatGPT_water_bowl_electronics_carrier.scad]
2026-07-16 Document restored SparkFun board locks
2026-07-16 Add files via upload
    50kg Loadcell Bracket versionF by patrick3345 on Thingiverse: https://www.thingiverse.com/thing:2624188
    [50kgLoadcell-VersionF-2021.skp, 50kgLoadcell-VersionF-2021.stl, 50kgLoadcell-VersionF-2021_v1-Fusion360.f3d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]
2026-07-16 Add temporary load-cell STL payload part 1
2026-07-16 Add temporary load-cell STL payload part 2
2026-07-16 Add temporary load-cell STL payload part 3
2026-07-16 Add temporary 2021 load-cell STL payload part 1
2026-07-16 Add temporary 2021 load-cell STL payload part 2
2026-07-16 Add temporary 2021 load-cell STL payload part 3
2026-07-16 Replace load-cell brackets with repaired STL files
    [50kgLoadcell-VersionF-2021.stl, 50kgLoadcell-VersionF.stl]
2026-07-16 Rename load-cell bracket folder and document hardware
    [50kgLoadcell-VersionF-2021.skp, 50kgLoadcell-VersionF-2021.stl, 50kgLoadcell-VersionF-2021_v1-Fusion360.f3d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]
2026-07-16 Expose raw HX711 as disabled diagnostic sensor
2026-07-16 Remove ChatGPT prefixes from project filenames
    [water_bowl_electronics_carrier.scad]
2026-07-16 Fix HX711 median filter startup setting
    [esphome_water_bowl.yaml]
2026-07-17 Replace SparkFun snap tabs with direct M3 screw bosses
    [water_bowl_electronics_carrier.scad]
2026-07-17 Document V36 direct-threaded M3 board mounting
2026-07-17 Refine carrier design for V37
    [water_bowl_electronics_carrier.scad]
2026-07-17 Document LeMotech enclosure ASIN
    [water_bowl_electronics_carrier.scad]
2026-07-17 Document LeMotech enclosure ASIN in README
2026-07-17 Improve V37 carrier variable documentation
    [water_bowl_electronics_carrier.scad]
2026-07-17 Increase SparkFun M3 pilot holes for V38
    [water_bowl_electronics_carrier.scad]
2026-07-17 Document V38 M3 pilot-hole sizing
2026-07-17 Increase OpenSCAD facet count to 96
    [water_bowl_electronics_carrier.scad]
2026-07-24 Add clip-on fountain tube mount
    [water_bowl_fountain_mount.scad]
2026-07-24 Document fountain tube mount
2026-07-27 Relieve HX711 support pads for underside pins
    [water_bowl_electronics_carrier.scad]
2026-07-27 Correct HX711 relief orientation for V40
    [water_bowl_electronics_carrier.scad]
2026-07-30 Add corner hole-marking jig v1.0
    [water_bowl_corner_hole_jig_v1.0.scad, water_bowl_corner_hole_jig_v1.0.stl]
2026-07-30 Remove generated jig STL
    [water_bowl_corner_hole_jig_v1.0.stl]
2026-07-30 Rename corner jig source to stable filename
    [water_bowl_corner_hole_jig.scad]
2026-07-30 Remove version from corner jig filename
    [water_bowl_corner_hole_jig_v1.0.scad]
2026-07-31 Revise fountain mount for thin bowl lip
    [water_bowl_fountain_mount.scad]
2026-07-31 Add enclosure side-hole pilot jig
    [water_bowl_enclosure_pilot_hole_jig.scad]
2026-07-31 Document enclosure jigs
2026-07-31 Move enclosure pilot-hole jig to hardware/jigs
    [water_bowl_enclosure_pilot_hole_jig.scad]
2026-07-31 Remove old enclosure-local jig path
    [water_bowl_enclosure_pilot_hole_jig.scad]
2026-07-31 Remove obsolete enclosure jigs folder
